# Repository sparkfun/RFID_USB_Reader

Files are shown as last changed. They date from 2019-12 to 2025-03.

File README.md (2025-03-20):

SparkFun RFID USB Reader
=========================

SparkFun RFID USB Reader

[*SparkFun RFID USB Reader (SEN-09963)*](https://www.sparkfun.com/products/9963)

The SparkFun RFID USB Reader is a simple to use, USB to serial base unit for the ID-3LA, ID-12LA, and ID-20LA readers.

Documentation
-------------
- **[Hookup Guide](https://learn.sparkfun.com/tutorials/sparkfun-rfid-starter-kit-hookup-guide)** - The hookup guide for the SparkFun RFID USB Reader

Repository Contents
-------------------
- **[/Hardware](/Hardware/)** - Hardware design files (.brd, .sch)
- **[/Production](/Production/)** - Production files

Product Variants
----------------
- [SEN-28020](https://www.sparkfun.com/sparkfun-rfid-usb-c-reader.html) - USB-C connector and CH340C converter
- [SEN-09963](https://www.sparkfun.com/sparkfun-rfid-usb-reader.html) - Original product *(w/ USB mini-B connector and FTDI converter)*

Version History
---------------
- [v10](https://github.com/sparkfun/RFID_USB_Reader/releases/tag/v10) - Initial Release

License Information
-------------------

This product is ***open source***!

Please review the [`LICENSE.md`](./LICENSE.md) file for license information.

If you have any questions or concerns about licensing, please contact technical support on our [SparkFun forums](https://forum.sparkfun.com/viewforum.php?f=152).

Distributed as-is; no warranty is given.

- Your friends at SparkFun.

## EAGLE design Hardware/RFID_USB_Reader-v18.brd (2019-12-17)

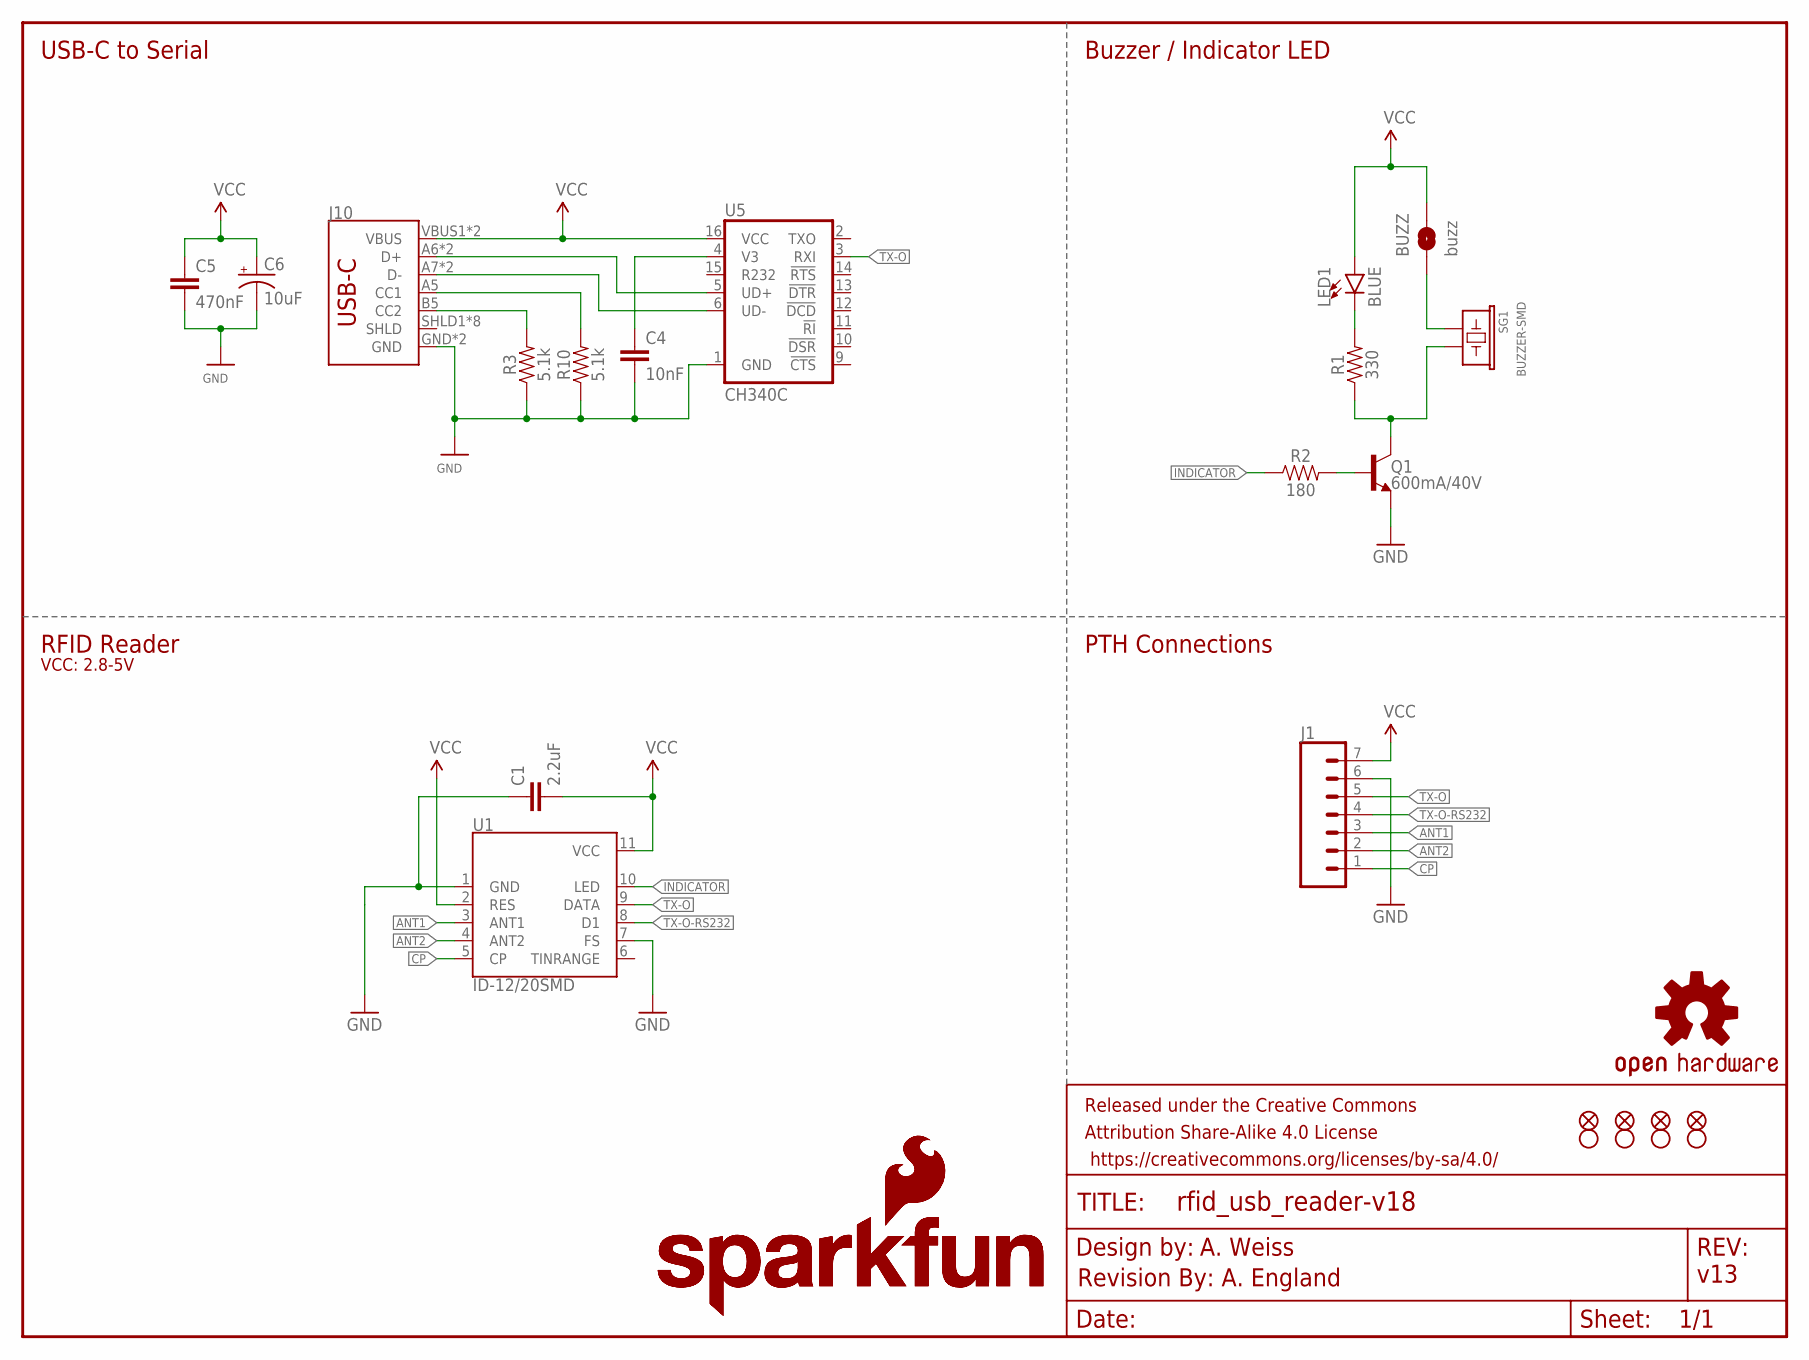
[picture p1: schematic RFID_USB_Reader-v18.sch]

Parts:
BUZZ: buzz; SMT-JUMPER_2_NO_NO-SILK
C1: 2.2uF; 0603
C4: 10nF; 0603
C5: 470nF; 0603
C6: 10uF; 0603-POLAR
FRAME1: FRAME-LETTER; CREATIVE_COMMONS
J1: CONN_07; 1X07
J10: USB_C2-LAYER; USB-C-16P
JP1, JP2, JP3, JP5: FIDUCIAL1X2; FIDUCIAL-1X2
LED1: BLUE; LED-0603
LOGO1, LOGO2: SFE_LOGO_NAME_FLAME.1_INCH; SFE_LOGO_NAME_FLAME_.1
LOGO3: OSHW-LOGOS; OSHW-LOGO-S
LOGO4: REVISION
Q1: 600mA/40V; SOT23-3
R1: 330; 0603
R2: 180; 0603
R3, R10: 5.1k; 0603
SG1: BUZZER-SMD; BUZZER-CCV
U1: ID-12/20SMD; ID-12_SMD
U5: CH340C; SO016
U$4, U$5, U$6, U$7: STAND-OFF

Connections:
ANT1: J1.3, U1.3 (ANT1)
ANT2: J1.2, U1.4 (ANT2)
CP: J1.1, U1.5 (CP)
GND: C1.1, C4.2, C5.2, C6.-, J1.6, J10.GND, J10.GND2 (GND), Q1.2 (E), R3.1, R10.1, U1.1 (GND), U1.7 (FS), U5.1 (GND)
INDICATOR: R2.1, U1.10 (LED)
unnamed: Q1.3 (C), R1.1, SG1.- (2)
unnamed: C4.1, U5.4 (V3)
unnamed: J10.A6 (D+), J10.B6 (D+), U5.5 (UD+)
unnamed: BUZZ.1, SG1.+ (1)
unnamed: J10.A5 (CC1), R10.2
unnamed: LED1.C, R1.2
unnamed: Q1.1 (B), R2.2
unnamed: J10.A7 (D-), J10.B7 (D-), U5.6 (UD-)
unnamed: J10.B5 (CC2), R3.2
TX-O: J1.5, U1.9 (DATA), U5.3 (RXI)
TX-O-RS232: J1.4, U1.8 (D1)
VCC: BUZZ.2, C1.2, C5.1, C6.+, J1.7, J10.VBUS1 (VBUS), J10.VBUS2 (VBUS), LED1.A, U1.2 (RES), U1.11 (VCC), U5.16 (VCC)

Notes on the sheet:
A. Weiss
A. England
v13
RFID Reader
USB-C to Serial
Buzzer / Indicator LED
PTH Connections
VCC: 2.8-5V

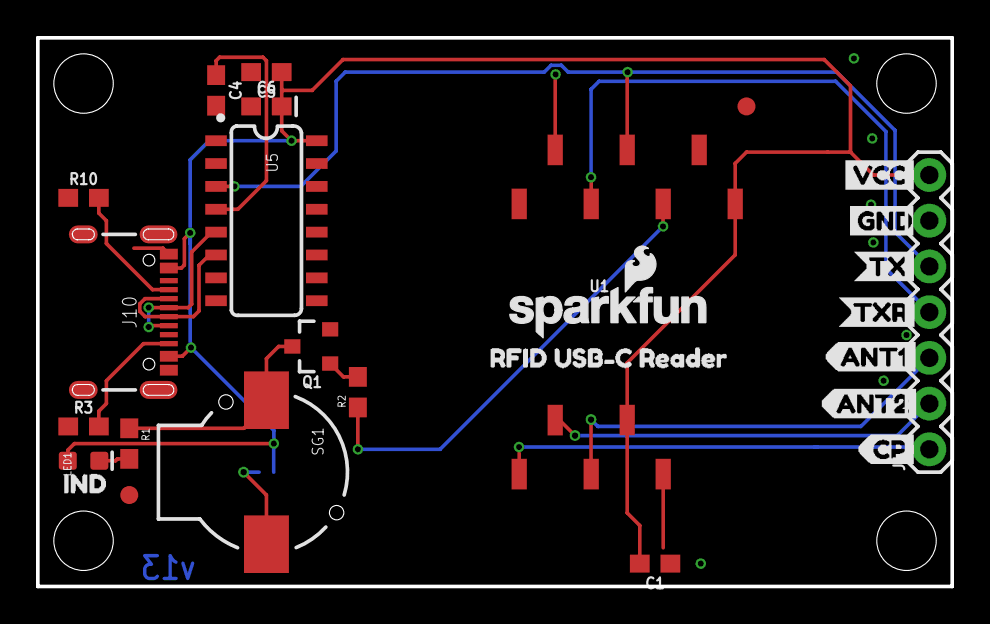
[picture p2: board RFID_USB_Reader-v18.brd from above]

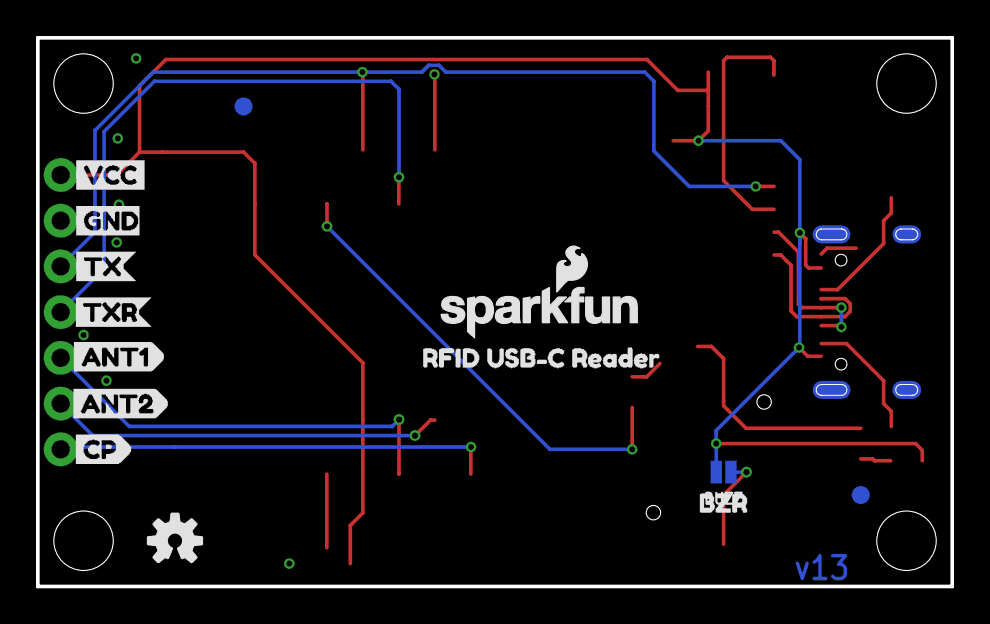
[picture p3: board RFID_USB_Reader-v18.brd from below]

Board: 2 copper layers, 50.8 x 30.5 mm, 47 parts (14 on the bottom side), 17 nets.

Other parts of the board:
U$1: CP5
U$3, U$13: GND1
U$8: BZR3
U$9: TX3
U$10: TXR4
U$11, U$12: VCC0
U$14: TX0
U$15: TXR1
U$16: CP2
U$17, U$18: RFID_USB#C_READER0
U$19: ANT11
U$20: ANT13
U$21: ANT22
U$22: ANT24
U$23: IND0

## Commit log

2015-03-10 Adding hardware files, updating README
    [RFID_USB_Reader-v18.brd, RFID_USB_Reader-v18.sch]
2019-12-05 revising to move plane and routing out from underneath of RFID reader, removing ant pin breakout
    [RFID_USB_Reader-v18.brd, RFID_USB_Reader-v18.sch]
2019-12-06 post checklist changes
    [RFID_USB_Reader-v18.brd, RFID_USB_Reader-v18.sch]
2019-12-06 post review changes
    [RFID_USB_Reader-v18.brd, RFID_USB_Reader-v18.sch]
2019-12-09 post QC checklist changes
    [RFID_USB_Reader-v18.GBL, RFID_USB_Reader-v18.GBO, RFID_USB_Reader-v18.GBS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]
2019-12-09 changing name to USB-C
    [RFID_USB_Reader-v18.brd]
2019-12-17 updating Buzzer and npn transistor to have PROD_ID
    [RFID_USB_Reader-v18.brd, RFID_USB_Reader-v18.sch]

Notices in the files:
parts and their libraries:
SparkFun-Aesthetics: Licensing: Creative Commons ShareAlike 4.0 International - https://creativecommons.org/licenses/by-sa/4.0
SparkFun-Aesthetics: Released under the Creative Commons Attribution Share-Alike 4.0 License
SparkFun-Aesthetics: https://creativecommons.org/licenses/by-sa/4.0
